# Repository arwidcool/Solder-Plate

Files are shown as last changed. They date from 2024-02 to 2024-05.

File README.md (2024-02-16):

# Solder Plate Controller with Detachable Hotplate

This repository contains the source code and design files for a Solder Plate Controller and detachable hotplate. The processor used is the ATmega4809 and is based on the work of DerSpatz. https://github.com/DerSpatz/PCB-reflow-solder-heat-plate

## Features
- Precise temperature control for soldering SMD components. with support of **up to 6 thermistors**.
- Cheap and widely available MCU- Atmega4809 and low BOM cost
- Custom PCB design with 2 versions: single area control (Completed) and 4 independent heating zones control(In works)
- Detacabale hotplate allows for use of new heatplate designs including larger ones
- Programming via USB
- PlatformIO integration for streamlined development.
- wifi via esp8266-12f module (with wifi version - In Development).
- Based on Reflow Hotplate by DerSpatz with some improvements
- Oled for menu navigation, debugging, and thermistor info
- TFT for reflow profile target and actual temp
- 4 buttons for menu navigation
- Current sense IC for current monitoring
- 3 indicator LED's. They work for both menu and REFLOW profiles (blinking while on the current stage and solid once the profile stage is complete).
- Buzzer for complete notification
- Buck- Converter for input voltage, allowing up to 24V in
- 24V+ rated input voltage stage components allowing  up to 24V to be used (Depending on powersupply trip option the "max" pwm needs to be lowered to not trip power suppply safety)
- Optional fan for cooling stage (not yet installed)
= Included are files for a case and a guard for the detachable plate terminal guard.

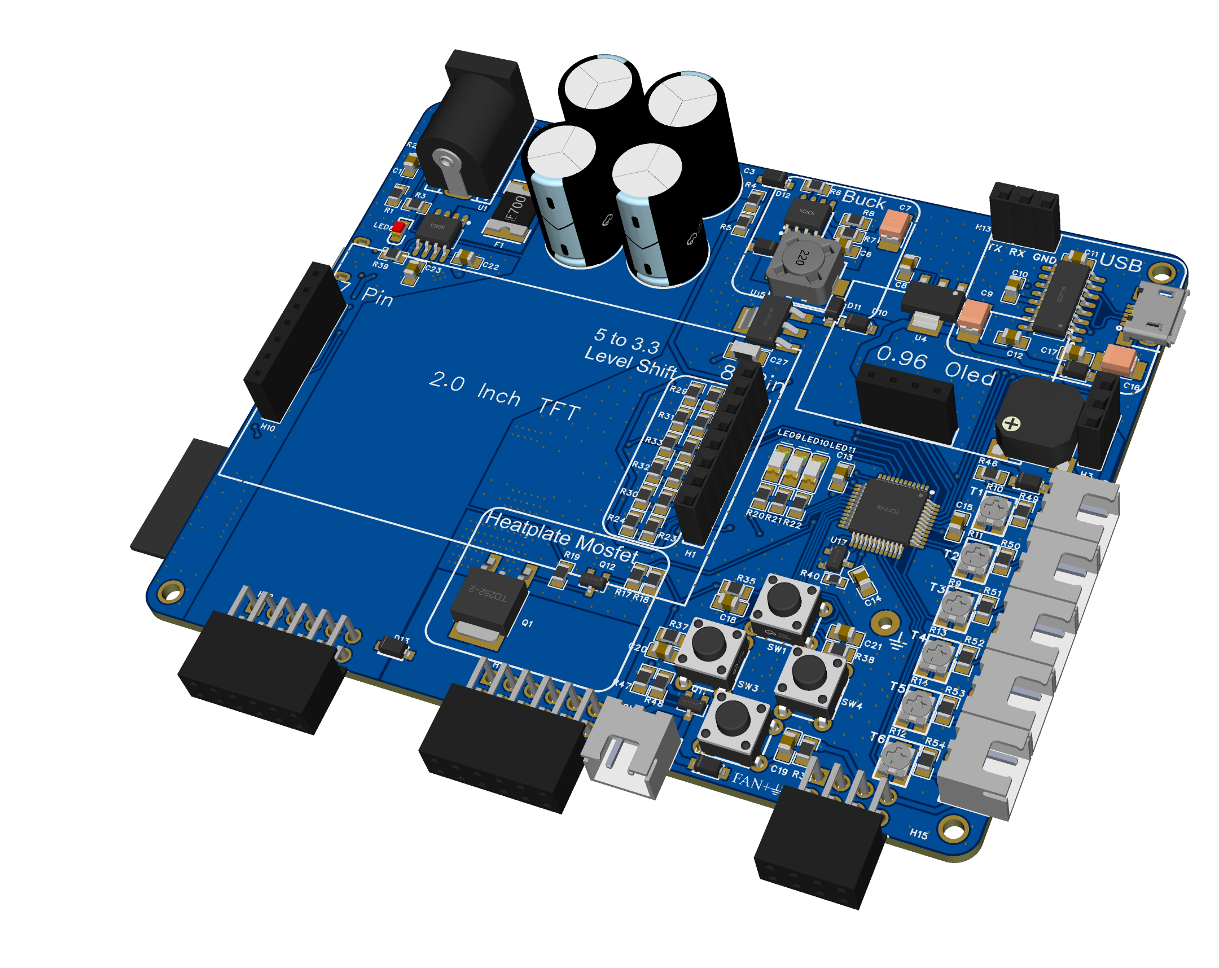
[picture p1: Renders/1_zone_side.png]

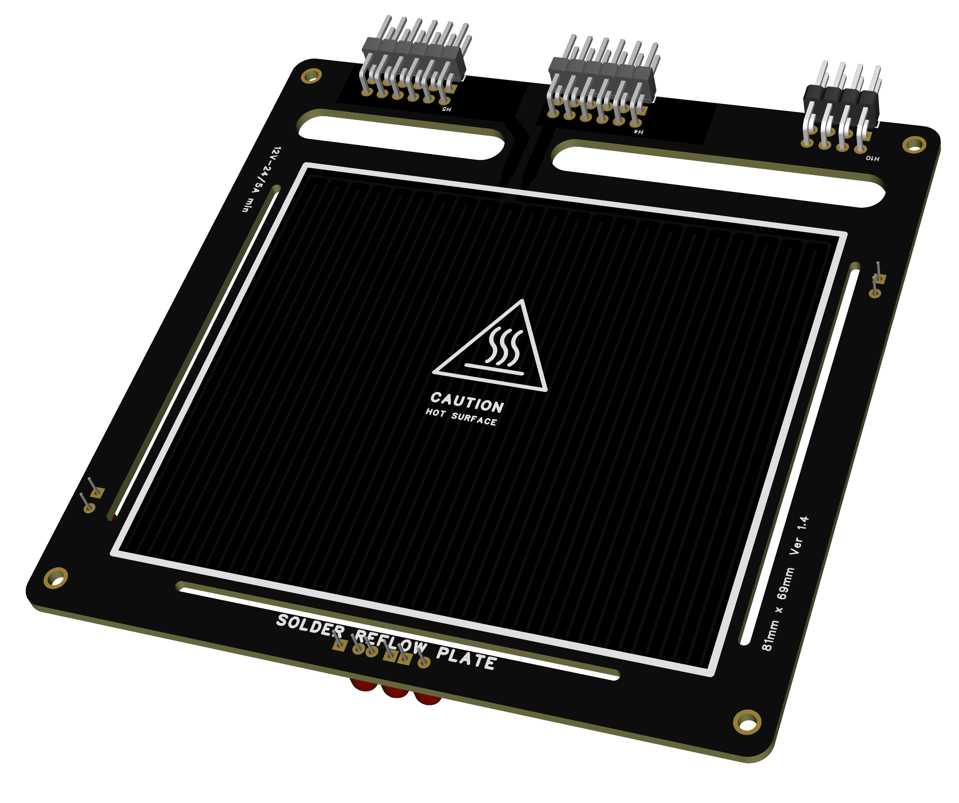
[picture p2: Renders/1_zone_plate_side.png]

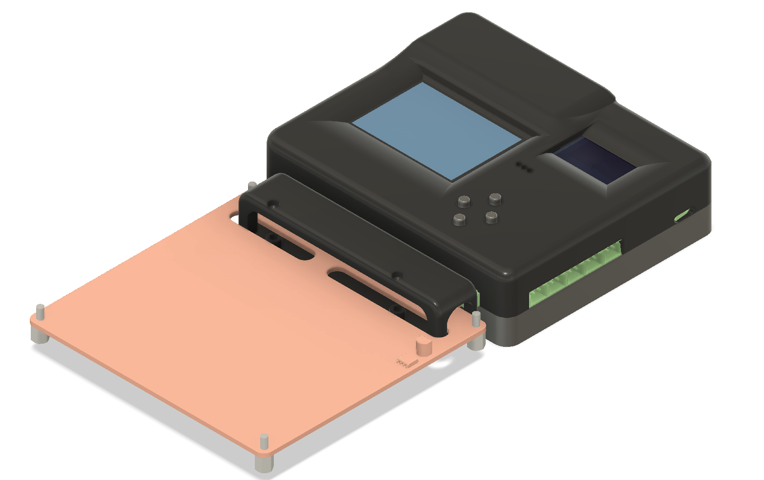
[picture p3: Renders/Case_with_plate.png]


## Getting Started

### Prerequisites

- PlatformIO Core or PlatformIO IDE.
- ATmega4809 microcontroller and all the BOM components
- Basic soldering tools and electronic assembly skills.
- Access to a PCB manufacturing service or soldering equipment (solder paste, hot air gun, tweezers)
- Some basic technical skills

### Hardware Setup

*** MAKE SURE YOU ORDER THE HOTPLATE IN BLACK. IT WILL NOT DISCOLOR AND HOLDS UP A LOT BETTER TO HEAT CYCLES ***

1. **PCB Fabrication:** Fabricate the PCB using the provided gerber files. You can use these to order the naked PCB from services like JLCPCB. 
2. **Component Assembly:** Solder the components onto the PCB as per the schematic or choose a SMT assembly service like the ones from JLCPCB
3. **Power Supply Connection:** Choose a suitable power supply. 12V 5A tested, 24v 5A compatible. Use of more then 5A requires a appropriate FUSE to be chosen and solder on place of F1

### Preparing the ATmega4809

Before programming the ATmega4809, it needs to be flashed with a default bootloader.

1. **Bootloader Flashing:**

Same process as DerSpatz Solder plate with some changes to the bootloader settingffs:

The MCU can be programmed with JTAG2UPDI (https://github.com/ElTangas/jtag2updi). For programming, you need an Arduino with ATMEGA328p (Uno or Nano), some wires, a 4.7k resistor and a 10µF capacitor or 120 Ohm resistor to disable the auto-reset.

JCM from the Discord explained the process pretty good:

- Download/Clone this project: https://github.com/ElTangas/jtag2updi and rename the folder "source" to "jtag2updi" (otherwise the Arduino IDE won't like it)
- Open jtag2updi/jtag2updi.ino in your Arduino IDE
- Configure the flasher options for your Arduino Nano and flash it
- Connect D6 of your Arduino Nano over the 4.7kOhm resistor to the UPDI pin of the board and 5V to 5V and GND to 0V
- Add the MegaCoreX hardware package to the Ardunio IDE (see https://github.com/MCUdude/MegaCoreX#how-to-install)
- Select the options for the programmer **(Board: ATmega4809, Clock: Internal 16 MHz, BOD: 2.6V or 2.7V, EEPROM: retained, Pinout: 48 pin standard, Reset pin: Reset, Bootloader:Optiboot:Uart0(Defualt pins))** and select the port of your Ardunio Nano as Port
- Make sure the programmer selected is SerialUPDI or JTAG2UPDI
- Select Burn Bootloader and see if it runs through

2. **MicroUSB Programming And Firmware Upload:**

   - **Using Platformio:**
   1. After flashing the bootloader, the ATmega4809 can be programmed via the microUSB connection using PlatformIO by building the project and upload
  
   - **Using AVRDude:**
   1. Folow instructions on : https://github.com/ElTangas/jtag2updi?tab=readme-ov-file#using-with-avrdude
   2. Example : avrdude -c jtag2updi -P com7 -p t1614
  
   - **Using AVRDUDESS (AVRDUDE with GUI interface) -- This section many not be completley finished:**
   1. Download and install AVRDUDE https://download-mirror.savannah.gnu.org/releases/avrdude/
   2. Download AVRDUDESS : https://github.com/ZakKemble/AVRDUDESS
   3. Choose the programmer as arduino
   4. Choose the MCU as ATmega4809
   5. Choose the COMPORT where the Solder Plate Controller is connected to
   6. Choose the Flash binary in the programming directory -> set to Write
   7. Choose "Write" on the Flash option and press "Go"

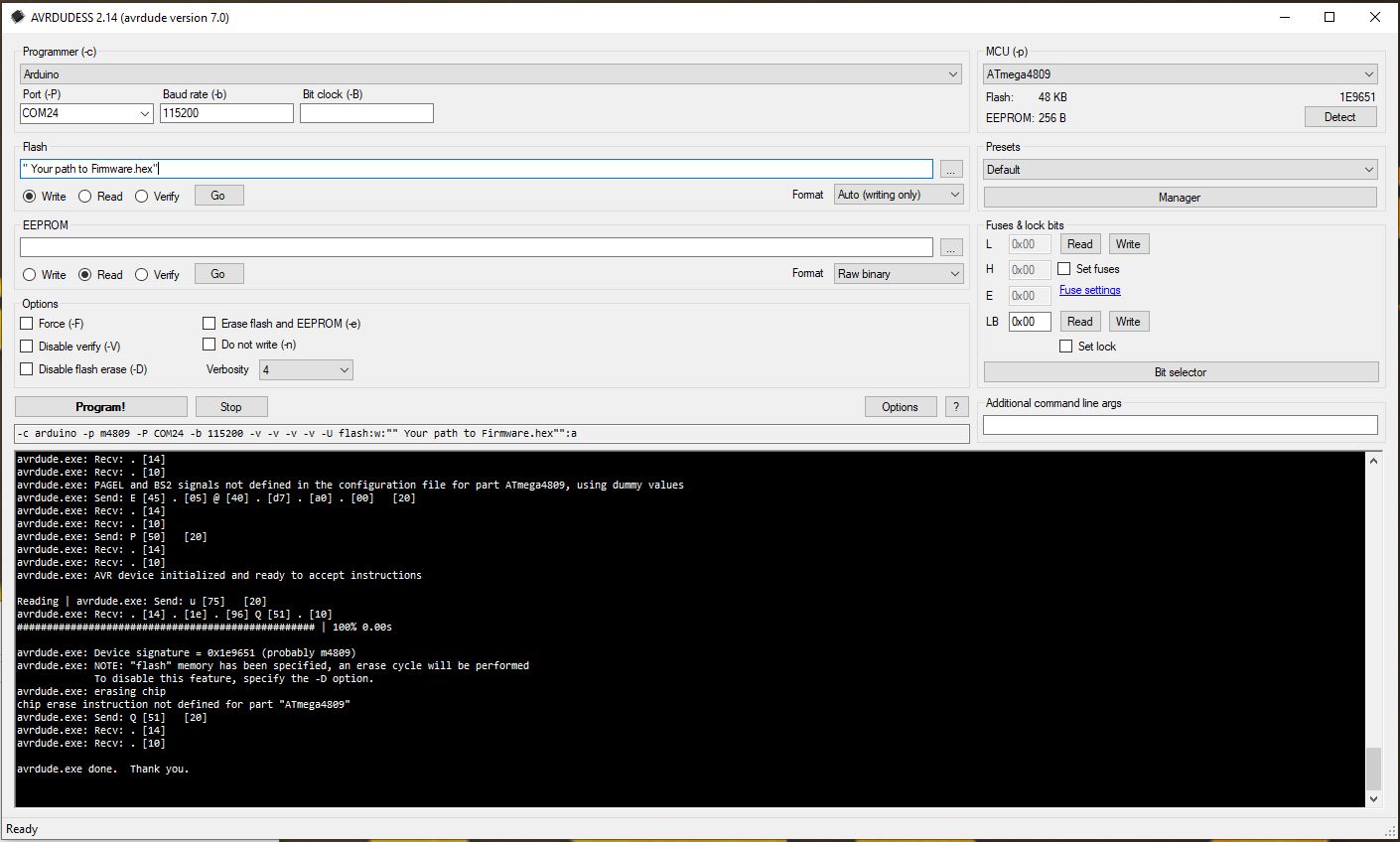
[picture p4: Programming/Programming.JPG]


3. **Setting up the controller**
   1. Order 100K NTC Glass thermistors  Use for dev was : 100K Ohm Resistor NTC 3950->  https://www.aliexpress.com/item/32862228715.html?spm=a2g0o.order_list.order_list_main.11.1f0a1802Lw8YGL
   2. Using either the potentiometer or soldering the resistor beside it choose the resistor reference value (2.5Kohm is standard)
   3. You can modify the thermistor settings in Global.ccp file, it is all explained in there
   4. Attach the sensors to the hotplate using High temp Kapton Tape
   5. Reccomended is 3 sensors on the bottom middle of plate all with 3 different refernece resistor values for accuracy across all temperature ranges and 1 thermistor held by a pair of helping hangs placed so the head touches somewhere on the PCB to be refllowed
   By default this is set as thermistor 1:
   6. Link to 2.0 inch TFT -> https://www.aliexpress.com/item/1005002363748586.html?spm=a2g0o.order_list.order_list_main.5.165d1802Amz1I7  (8 pin version) -> 7 Pin version can also be used 
   7. Link to 0.96 OLED -> https://www.aliexpress.com/item/32957309383.html?spm=a2g0o.order_list.order_list_main.17.662c1802iqqiSE  (Choose OLD design SSD1306)

   *** IMPORTANT: Thermistors 1 is ONLY available on the hotplate. Thermistor 6 is only available on the controller via connector 5**

   You can solder the thermistors directly on the hotplatte or use them with the connector. Please update the thermistor settings to the way you have them set-up.

   Here are the defualt thermistor settings, The assume that the thermistors are soldered on the plate for 1,2,3: 
   Thermistors 6 on the connector number 5, touching the PCB to be soldered.

   Thermistor thermistor1(THERMISTOR1_PIN, 2545, ThermistorZ_Placement::ON_PCB, ThermistorXY_Placement::MIDDLE);          // -> 2545ohm set refrence -> This thermistor is set directly touching the PCB to be soldered
   Thermistor thermistor2(THERMISTOR2_PIN, 9100, ThermistorZ_Placement::BOTTOM, ThermistorXY_Placement::MIDDLE_LOW_TEMP);          //- > 9100 ohm set refrence Best accuracy around 90C -> This thermistor is used for the lower end of the temp scale  
   Thermistor thermistor3(THERMISTOR3_PIN, 2040, ThermistorZ_Placement::BOTTOM, ThermistorXY_Placement::MIDDLE); // -> 2.5Kohm best middleground
   Thermistor thermistor4(THERMISTOR4_PIN, 564, ThermistorZ_Placement::BOTTOM, ThermistorXY_Placement::MIDDLE_HIGH_TEMP); //-> 564Kohm set refrence // 564R reference = Best accuracy around 210C

   If you wish to only use the connectors use 2,3,4 and update the Globals .cpp to match your settings
      
   The set resistence is measured between a GND point anywhere on the board and the LEFT pin of the connector with the thermistor UNPLUGGED and the MODULE POWERED OFF!!!!

   you can measure and set those to the preset values or modify the values in globals.ccp to match your thermistors.

   If a thermistor is set to bottom a automatic scaling factor for the difference difference in plate temp is set that was aquired through lots of datalogging and computations

   If a thermistor is set to SIDE there is no scaling factor and will throw off the reading acorss the center of the plate (overall will be lower)

   When using the Thermistor with placement "ON_PCB" That thermistor has a weighting factor of 10 and has the biggest effect on the read temperature.

   The normal weighting factor is between 0.1 and 1.5 for the others.

### Software Installation

1. **Clone the Repository:**
   ```bash
   git clone https://github.com/arwidcool/Solder-Plate
   cd Solder-Plate
2. **Import in vscode**
To open a PlatformIO project in VSCode with the PlatformIO extension, follow these steps:

1. Launch VSCode and ensure that you have the PlatformIO extension installed. If not, you can install it from the VSCode marketplace.
2. Open the VSCode command palette by pressing Ctrl+Shift+P (Windows/Linux) or Cmd+Shift+P (Mac).
3. In the command palette, type "PlatformIO: Open" and select the "PlatformIO: Open" command from the list.
4. Navigate to the root folder of your PlatformIO project using the file explorer that appears.
5. Select the folder and click "Open" to open the PlatformIO project in VSCode.

### Usage

Power On: Connect the controller with a 12V 5A(Tested working) or 24V 5A PSU (Untested)
Set Profile: Navigate the menu and choose the desired reflow profile
Start Soldering: Place your PCB and components on the hotplate and start the profile

### Customization

Feel free to modify the firmware and PCB design to suit your specific needs.

### Contributing
Contributions are welcome. Please follow standard procedures for contributing to open-source projects.

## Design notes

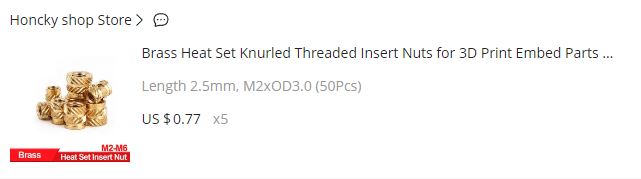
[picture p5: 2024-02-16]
Hardware/Case 3D Files/Inserts.JPG

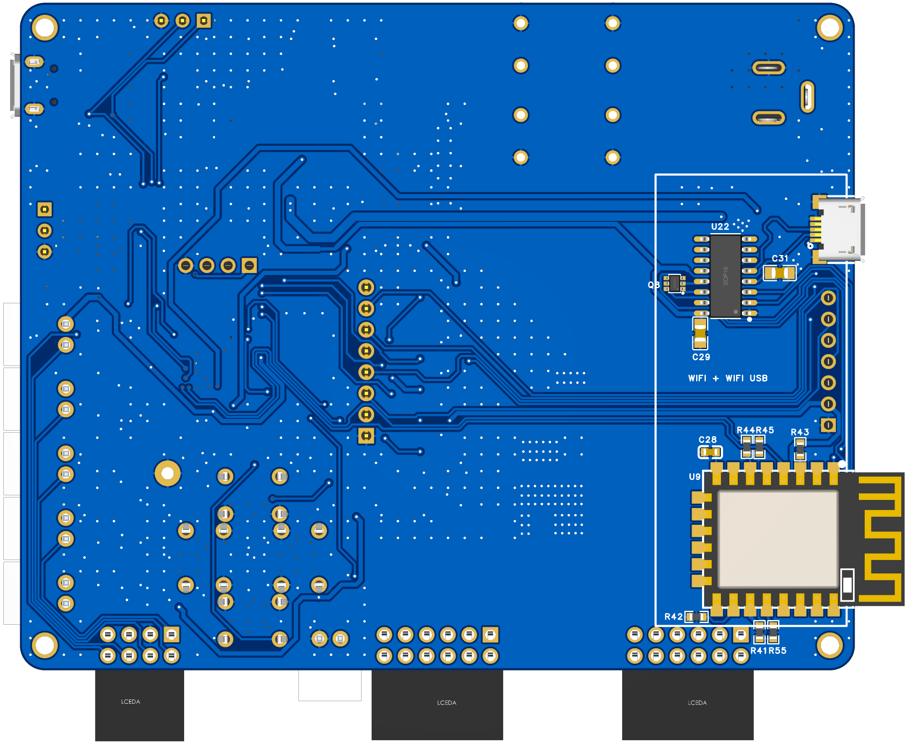
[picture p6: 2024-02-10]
Renders/1 zone back.png

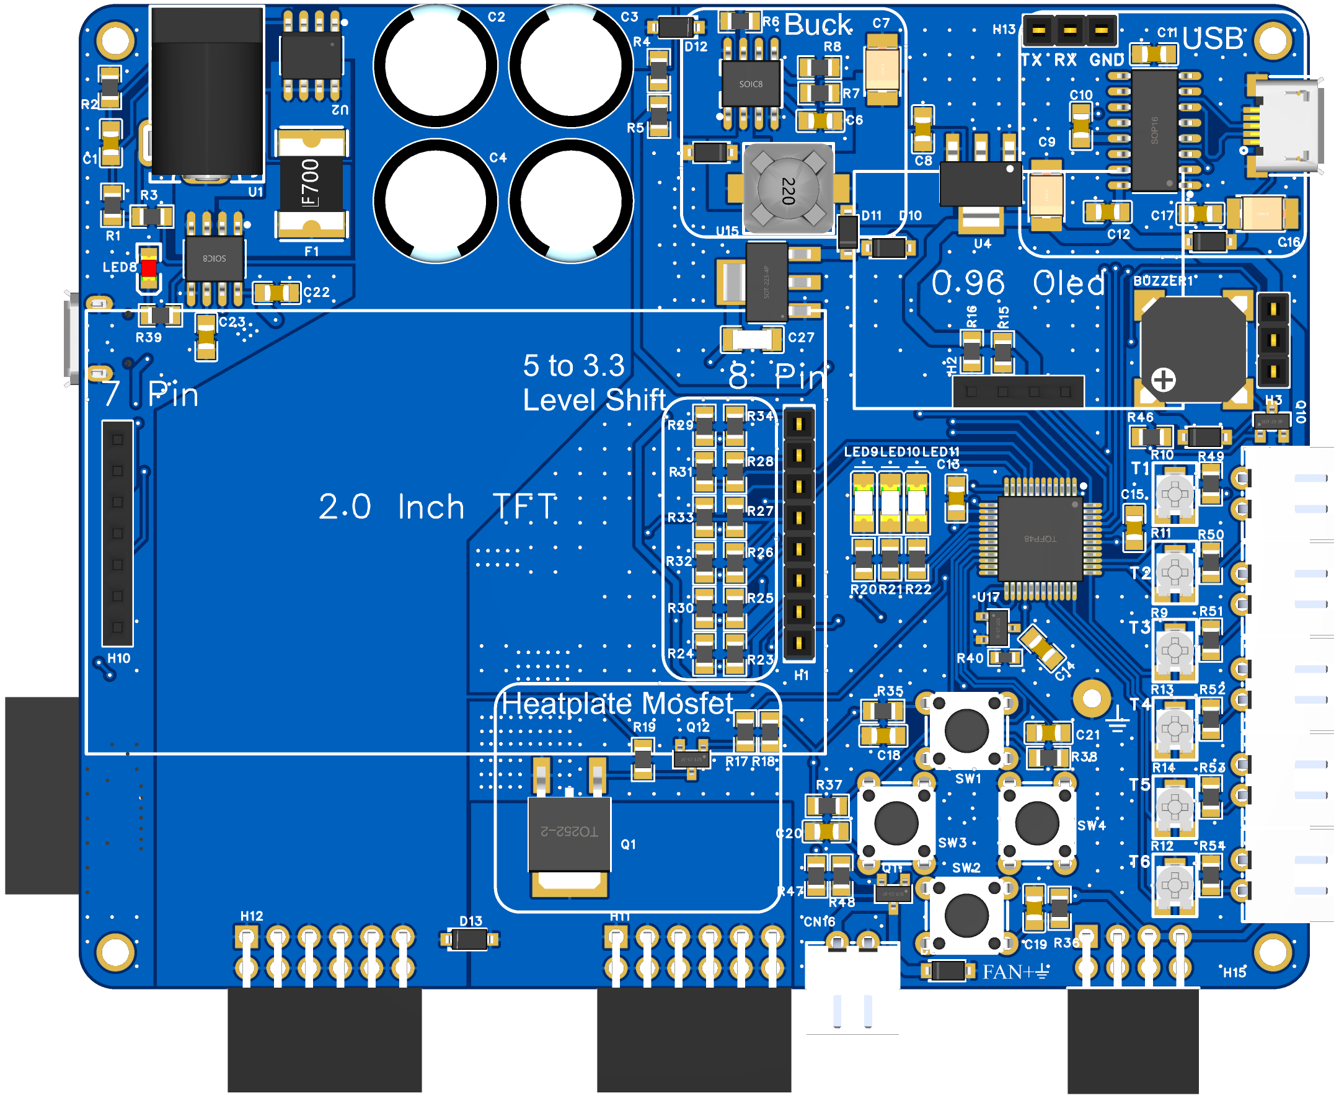
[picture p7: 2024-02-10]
Renders/1 zone top.png

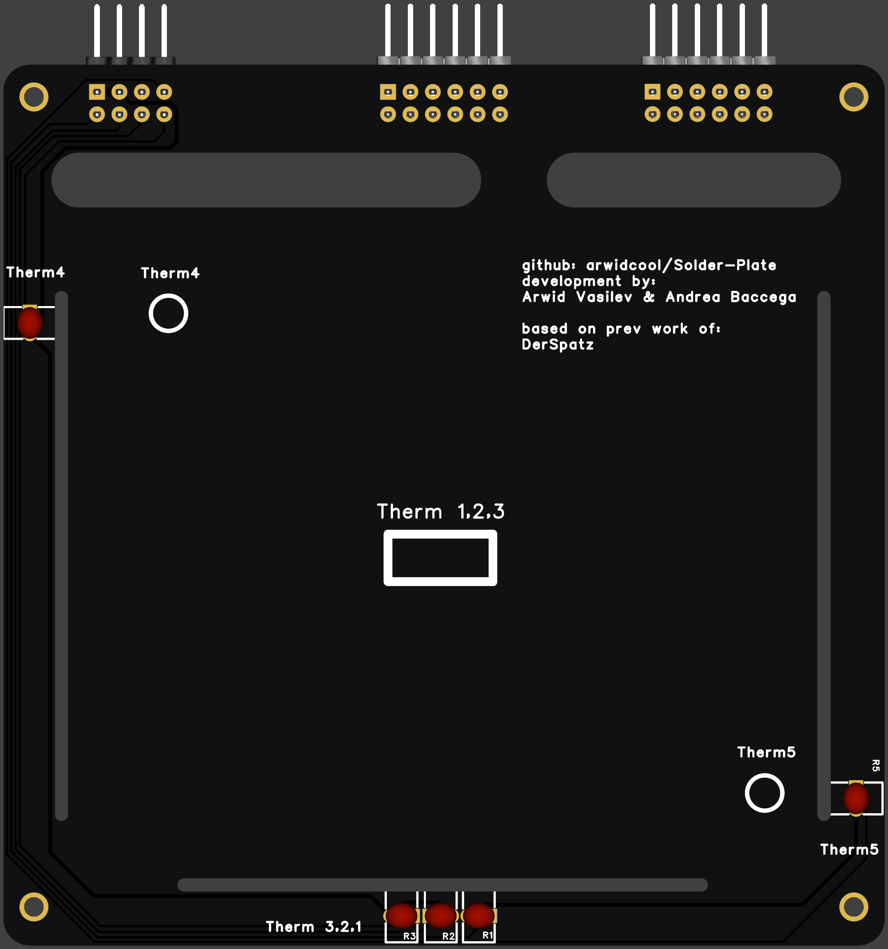
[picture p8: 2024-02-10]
Renders/1 zone plate back.png

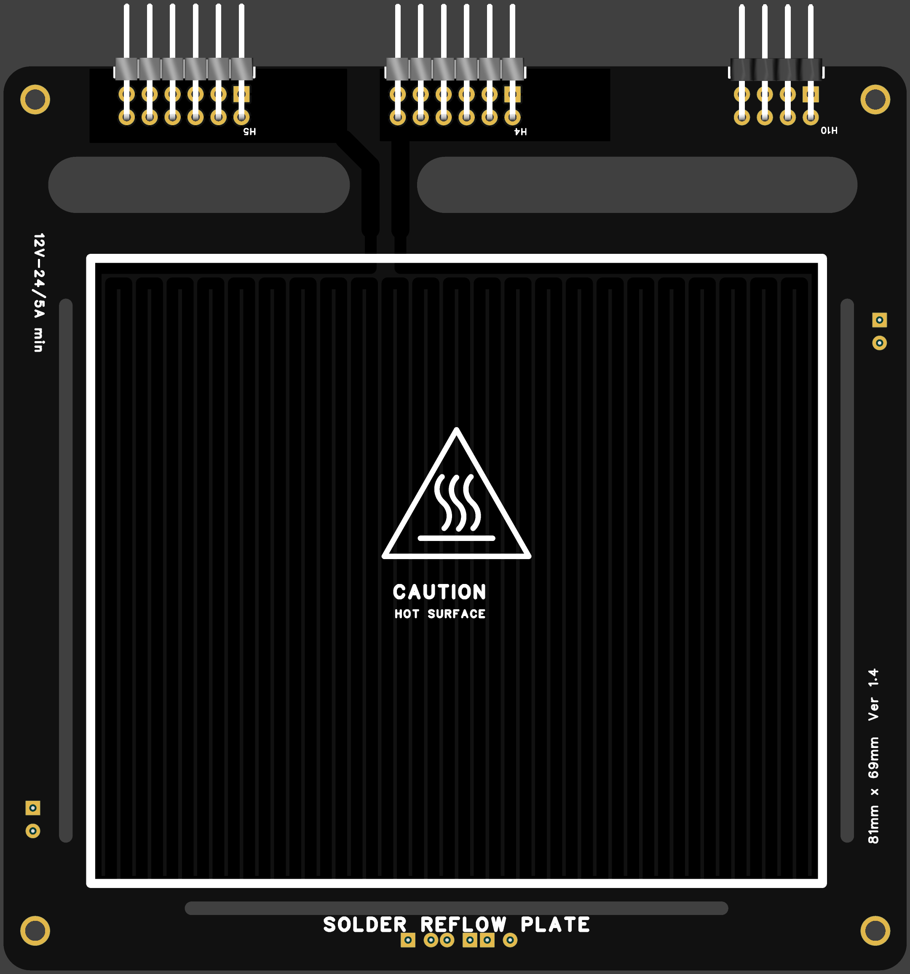
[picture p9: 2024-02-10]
Renders/1_zone_plate_top.png

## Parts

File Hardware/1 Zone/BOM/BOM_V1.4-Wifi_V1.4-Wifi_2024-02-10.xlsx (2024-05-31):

No. | Quantity | Comment | Designator | Footprint | Value | Manufacturer Part | Manufacturer | Supplier Part | Supplier | Pins | Supplier Footprint | Rated Voltage | Device | LCSC Price
1 | 1 | 2700Hz | BUZZER1 | BUZ-SMD_4P-L8.5-W8.5-P8.50-BR | 2700Hz | MLT-8530 | 华能 | C94599 | LCSC | 4 | SMD | 3.6V | MLT-8530 | 0.2334
2 | 1 | 10uF | C1 | C0805 | 10uF |  |  |  |  | 2 | 0805 |  | CAP_0805
3 | 4 | 680uF | C2,C3,C4,C5 | CAP-TH_BD10.0-P5.00-D1.0-FD | 680uF | GR687M035G20RR0VL4FP0 | CX(承兴) | C23777 | LCSC | 2 | 插件,D10xL20mm |  | GR687M035G20RR0VL4FP0
4 | 1 | 220pF | C6 | C0805 | 220pF |  |  |  |  | 2 | 0805 |  | CAP_0805
5 | 3 | 100uF | C7,C9,C16 | CAP-SMD_L3.5-W2.8-R-RD | 100uF | TC212B107M010B | Sunlord(顺络) | C124859 | LCSC | 2 | CASE-B-3528 |  | TC212B107M010B | 0.2471
6 | 1 | 22uF | C8 | C0805 | 22uF |  |  |  |  | 2 | 0805 |  | CAP_0805
7 | 13 | 100nF | C10,C11,C12,C13,C14,C15,C18,C19,C20,C21,C22,C29,C31 | C0805 | 100nF |  |  |  |  | 2 | 0805 |  | CAP_0805
8 | 1 | 4.7uF | C17 | C0805 | 4.7uF |  |  |  |  | 2 | 0805 |  | CAP_0805
9 | 1 | 1nF | C23 | C0805 | 1nF |  |  |  |  | 2 | 0805 |  | CAP_0805
10 | 1 | 100uF | C27 | C1206 | 100uF | CL31A107MQHNNNE | SAMSUNG(三星) | C15008 | LCSC | 2 | 1206 |  | CL31A107MQHNNNE
11 | 1 | 100nF | C28 | C0603 | 100nF |  |  |  |  | 2 | 0603 |  | CAP_0603
12 | 6 | HX25003-2WAP | CN11,CN12,CN13,CN14,CN15,CN16 | CONN-TH_2P-P2.50_HX25003-2WAP |  | HX25003-2WAP | HX(红星) | C442326 | LCSC | 2 | 弯插,P=2.5mm |  | HX25003-2WAP | 0.0131
13 | 6 | MBR0520 | D1,D6,D7,D8,D10,D11 | SOD-123_L2.8-W1.8-LS3.7-RD |  | MBR0520 | CJ(江苏长电/长晶) | C77335 | LCSC | 2 | SOD-123 |  | MBR0520_C77335 | 0.0335
14 | 2 | B5819W | D12,D13 | SOD-123_L2.7-W1.6-LS3.7-RD-1 |  | B5819W |  | C179553 | LCSC | 2 | SOD-123 |  | B5819W
15 | 1 | SMD500L-30V | F1 | F2920 |  | SMD500L-30V | 台湾陆海 |  |  | 2 | 2920 |  | SMD250L-30V
16 | 1 |  | H1 | HDR-TH_8P-P2.54-V-F-1 |  |  |  |  |  | 8 | Through |  | HDR-F_2.54_1x8P
17 | 1 | 2.54-1*4P母 | H2 | HDR-TH_4P-P2.54-V-F |  | 2.54-1*4P母 | BOOMELE(博穆精密) | C2718488 | LCSC | 4 | Through |  | HDR-F_2.54_1x4P | 0.0436
18 | 2 | PM254V-11-03-H85 | H3,H13 | HDR-TH_3P-P2.54-V-F |  | PM254V-11-03-H85 | XFCN(兴飞) | C541850 | LCSC | 3 | Through |  | HDR-F_2.54_1x3P | 0.0948
19 | 1 | B-2200S07P-A120 | H10 | HDR-TH_7P-P2.54-V-F |  | B-2200S07P-A120 | Ckmtw(灿科盟) | C124418 | LCSC | 7 | Through |  | HDR-F_2.54_1x7P | 0.1426
20 | 2 | A2541HWR-2x6P | H11,H12 | HDR-TH_12P-P2.54-H-F-R2-C6-S2.54-W10.2 |  | A2541HWR-2x6P | CJT(长江连接器) | C5333437 | LCSC | 12 | 弯插,P=2.5mm |  | A2541HWR-2x6P_1 | 0.2818
21 | 1 | A2541HWR-2x4P | H15 | HDR-TH_8P-P2.54-H-F-R2-C4-S2.54-W10.2 |  | A2541HWR-2x4P | CJT(长江连接器) | C239355 | LCSC | 8 | 弯插,P=2.54mm |  | A2541HWR-2x4P | 0.1904
22 | 1 | 220uH | L1 | IND-SMD_L7.3-W7.3_CDRH74 | 220uH | 220uH (CD74R-221) | https://www.aliexpress.com/item/1005005453639618.html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 | AliExpress | N/A | 2 | SMD,7.3x7.3mm |  | CDRH74-221MT
23 | 1 |  | LED8 | LED0805-RD_GREEN |  |  |  |  |  | 2 | 0805 |  | LED_0805-R
24 | 1 | LED_Y | LED9 | LED1206-RD |  | LED_Y | 国星光电 | C130716 | LCSC | 2 | 1206 |  | NCD1206O1 | 0.0356
25 | 1 | LED_R | LED10 | LED1206-RD |  | LED_R | 国星光电 | C130716 | LCSC | 2 | 1206 |  | NCD1206O1 | 0.0356
26 | 1 | LED_G | LED11 | LED1206-RD |  | LED_G | 国星光电 | C130716 | LCSC | 2 | 1206 |  | NCD1206O1 | 0.0356
27 | 1 | AOD4184A | Q1 | TO-252-2_L6.6-W6.1-P4.57-LS9.9-TL-CW |  | AOD4184A | AOS | C99124 | LCSC | 3 | TO-252-2(DPAK) |  | AOD4184A | 0.3088
28 | 1 | UMH3NTN | Q8 | SOT-363_L2.0-W1.3-P0.65-LS2.1-TL |  | UMH3NTN | ROHM(罗姆) | C123008 | LCSC | 6 | SOT-323-6 |  | UMH3NTN | 0.0431
29 | 1 | IRLML2502 | Q10 | SOT-23_L2.9-W1.3-P1.90-LS2.4-BR |  | IRLML2502 | UMW(友台半导体) | C347503 | LCSC | 3 | SOT-23 |  | IRLML2502_C347503 | 0.0707
30 | 1 | SI2300 | Q11 | SOT-23-3_L2.9-W1.3-P0.95-LS2.4-BR |  | SI2300 | KUU | C2985622 | LCSC | 3 | SOT-23 |  | SI2300 | 0.0273
31 | 1 | S8050 | Q12 | SOT-23-3_L2.9-W1.3-P1.90-LS2.4-BR |  | S8050 | JSMSEMI(杰盛微) | C916390 | LCSC | 3 | SOT-23 |  | S8050_C916390 | 0.0050
32 | 2 | 47R | R1,R3 | R0805 | 47R |  |  |  |  | 2 | 0805 |  | Res_0805
33 | 14 | 10K | R2,R18,R24,R29,R30,R31,R32,R33,R35,R36,R37,R38,R46,R48 | R0805 | 10K |  |  |  |  | 2 | 0805 |  | Res_0805
34 | 10 | 4.7K | R4,R15,R16,R19,R23,R25,R26,R27,R28,R34 | R0805 | 4.7K |  |  |  |  | 2 | 0805 |  | Res_0805
35 | 5 | 1K | R5,R17,R20,R21,R39 | R0805 | 1K |  |  |  |  | 2 | 0805 |  | Res_0805
36 | 1 | .33R | R6 | R0805 | .33R |  |  |  |  | 2 | 0805 |  | Res_0805
37 | 1 | 7.5K | R7 | R0805 | 7.5K |  |  |  |  | 2 | 0805 |  | Res_0805
38 | 1 | 1.5K | R8 | R0805 | 1.5K |  |  |  |  | 2 | 0805 |  | Res_0805
39 | 6 | 15K | R9,R10,R11,R12,R13,R14 | RES-ADJ-SMD_VG039NCHXTB153 | 15K | VG039NCHXTB153 | HDK(北陆电气) |  | LCSC | 3 | SMD-3P,3x3.8mm |  | VG039NCHXTB153
40 | 4 | 2K | R22,R50,R51,R53 | R0805 | 2K |  |  |  |  | 2 | 0805 |  | Res_0805
41 | 1 | 750R | R40 | R0603 | 750R |  |  |  |  | 2 | 0603 |  | Res_0603
42 | 4 | 10K | R41,R42,R43,R55 | R0603 | 10K |  |  |  |  | 2 | 0603 |  | Res_0603
43 | 1 | 1K | R44 | R0603 | 1K |  |  |  |  | 2 | 0603 |  | Res_0603
44 | 1 | 3.6K | R45 | R0603 | 3.6K |  |  |  |  | 2 | 0603 |  | Res_0603
45 | 1 | 100R | R47 | R0805 | 100R |  |  |  |  | 2 | 0805 |  | Res_0805
46 | 3 | 15K | R49,R52,R54 | R0805 | 15K |  |  |  |  | 2 | 0805 |  | Res_0805
47 | 4 | K2-1102DP-G3SW-04 | SW1,SW2,SW3,SW4 | KEY-TH_4P-L6.0-W6.0-P4.50-LS6.5 |  | K2-1102DP-G3SW-04 | 韩国韩荣 | C136682 | LCSC | 4 | 插件 |  | K2-1102DP-G3SW-04 | 0.0541
48 | 1 | POWER-JACK | U1 | DC-IN-TH_POWER-JACK |  | POWER-JACK |  | C9900001795 | LCSC | 3 | DC-IN-TH_POWER-JACK |  | POWER-JACK
49 | 1 | AO4409 | U2 | SOP-8_L4.9-W3.9-P1.27-LS6.0-BL |  | AO4409 | TECHPUBLIC(台舟) | C7603375 | LCSC | 8 | SOP-8 |  | AO4409_C7603375 | 0.2139
50 | 1 | AMS1117-5.0 | U4 | SOT-223-3_L6.7-W3.7-P2.30-LS7.0-BR |  | AMS1117-5.0 | JSMSEMI(杰盛微) | C917153 | LCSC | 4 | SOT-223-3 |  | AMS1117-5.0_C917153 | 0.0957
51 | 1 | WT8266-S5ESP-12F | U9 | WIFIM-SMD_22P-L24.0-W16.0-P2.00 |  | WT8266-S5ESP-12F | Wireless-tag(启明云端) | C477829 | LCSC | 22 | SMD |  | WT8266-S5 ESP-12F | 2.4326
52 | 2 | CH340C | U11,U22 | SOP-16_L10.0-W3.9-P1.27-LS6.0-BL |  | CH340C | WCH(南京沁恒) | C84681 | LCSC | 16 | SOP-16 |  | CH340C | 0.4996
53 | 1 | AMS1117-3.3 | U15 | SOT-223-3_L6.5-W3.4-P2.30-LS7.0-BR |  | AMS1117-3.3 | AMS | C6186 | LCSC | 4 | SOT-223 |  | AMS1117-3.3_C6186
54 | 1 | MC34063ECD-TR | U16 | SOIC-8_L5.0-W4.0-P1.27-LS6.0-BL |  | MC34063ECD-TR | ST(意法半导体) | C65110 | LCSC | 8 | SOIC-8-150mil |  | MC34063ECD-TR
55 | 1 | LM4040DIM3-2.5+T | U17 | SOT-23-3_L2.9-W1.6-P1.90-LS2.8-BR |  | LM4040DIM3-2.5+T | ADI(亚德诺) | C2156551 | LCSC | 3 | SOT-23 |  | LM4040DIM3-2.5+T | 0.5378
56 | 1 | ATMEGA4809-AFR | U18 | TQFP-48_L7.0-W7.0-P0.50-LS9.0-BL |  | ATMEGA4809-AFR | MICROCHIP(美国微芯) | C189475 | LCSC | 48 | TQFP-48(7x7) |  | ATMEGA4809-AFR | 3.9137
57 | 1 | ACS712ELCTR-20A-T | U20 | SOIC-8_L4.9-W3.9-P1.27-LS6.0-BL |  | ACS712ELCTR-20A-T | ALLEGRO(美国埃戈罗) | C10681 | LCSC | 8 | SOP-8 |  | ACS712ELCTR-20A-T
58 | 2 | U254-051T-4BH83-S1S | USB1,USB2 | MICRO-USB-SMD_U254-051T-4BH83-S1S |  | U254-051T-4BH83-S1S | XKBConnectivity(中国星坤) | C319160 | LCSC | 6 | SMD |  | U254-051T-4BH83-S1S | 0.0672
59 | 2 | PZ254-2-06-W-8.5 | H4,H5 | HDR-TH_12P-P2.54-H-M-R2-C6-S2.54-N |  | PZ254-2-06-W-8.5 | HCTL(华灿天禄) | C2894986 | LCSC | 12 | 插件,P=2.54mm |  | PZ254-2-06-W-8.5 | 0.1796
60 | 1 | PZ254-2-04-W-8.5 | H10 | HDR-TH_8P-P2.54-H-M-R2-C4-S2.54-N |  | PZ254-2-04-W-8.5 | HCTL(华灿天禄) | C2894984 | LCSC | 8 | 插件,P=2.54mm |  | PZ254-2-04-W-8.5 | 0.1154

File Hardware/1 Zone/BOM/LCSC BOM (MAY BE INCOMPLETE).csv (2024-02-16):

LCSC Part Number | Manufacture Part Number | Manufacturer | Package | Customer # | Description | RoHS | Order Qty. | Min\Mult Order Qty. | Unit Price | Ext.Price | Product Link
C19078762 | 2920L500/24GR | LUTE | 2920 | F1 | 24V 5A 40A 10A 2920 Resettable Fuses ROHS | yes | 1 | 5 | 0.1849 | 0.18 | https://assets.lcsc.com/images/lcsc/96x96/20231113_LUTE-2920L500-24GR_C19078762_front.jpg
C2932476 | CL21A106KBYQNNE | Samsung Electro-Mechanics | 0805 |  | 50V 10uF X5R ±10% 0805 Multilayer Ceramic Capacitors MLCC - SMD/SMT ROHS | yes | 1 | 10 | 0.0686 | 0.07 | https://assets.lcsc.com/images/lcsc/96x96/20230122_Samsung-Electro-Mechanics-CL21A106KBYQNNE_C2932476_front.jpg
C61747 | CL21C221JBANNNC | Samsung Electro-Mechanics | 0805 |  | 50V 220pF C0G ±5% 0805 Multilayer Ceramic Capacitors MLCC - SMD/SMT ROHS | yes | 1 | 50 | 0.0137 | 0.01 | https://assets.lcsc.com/images/lcsc/96x96/20221230_Samsung-Electro-Mechanics-CL21C221JBANNNC_C61747_front.jpg
C6119901 | CGA0805X5R226M350MT | HRE | 0805 |  | 35V 22uF X5R ±20% 0805 Multilayer Ceramic Capacitors MLCC - SMD/SMT ROHS | yes | 1 | 5 | 0.1296 | 0.13 | https://assets.lcsc.com/images/lcsc/96x96/20230729_HRE-CGA0805X5R226M350MT_C6119901_front.jpg
C1711 | CL21B104KBCNNNC | Samsung Electro-Mechanics | 0805 |  | 50V 100nF X7R ±10% 0805 Multilayer Ceramic Capacitors MLCC - SMD/SMT ROHS | yes | 13 | 100 | 0.0069 | 0.09 | https://assets.lcsc.com/images/lcsc/96x96/20221227_Samsung-Electro-Mechanics-CL21B104KBCNNNC_C1711_front.jpg
C98192 | CL21A475KBQNNNE | Samsung Electro-Mechanics | 0805 |  | 50V 4.7uF X5R ±10% 0805 Multilayer Ceramic Capacitors MLCC - SMD/SMT ROHS | yes | 1 | 20 | 0.0238 | 0.02 | https://assets.lcsc.com/images/lcsc/96x96/20221231_Samsung-Electro-Mechanics-CL21A475KBQNNNE_C98192_front.jpg
C46653 | CL21B102KBCNNNC | Samsung Electro-Mechanics | 0805 |  | 50V 1nF X7R ±10% 0805 Multilayer Ceramic Capacitors MLCC - SMD/SMT ROHS | yes | 1 | 50 | 0.0079 | 0.01 | https://assets.lcsc.com/images/lcsc/96x96/20221230_Samsung-Electro-Mechanics-CL21B102KBCNNNC_C46653_front.jpg
C1591 | CL10B104KB8NNNC | Samsung Electro-Mechanics | 0603 |  | 50V 100nF X7R ±10% 0603 Multilayer Ceramic Capacitors MLCC - SMD/SMT ROHS | yes | 1 | 100 | 0.0026 | 0.01 | https://assets.lcsc.com/images/lcsc/96x96/20221227_Samsung-Electro-Mechanics-CL10B104KB8NNNC_C1591_front.jpg
C17714 | 0805W8F470JT5E | UNI-ROYAL(Uniroyal Elec) | 0805 |  | 125mW Thick Film Resistors 150V ±1% ±200ppm/? 47? 0805 Chip Resistor - Surface Mount ROHS | yes | 2 | 100 | 0.0018 | 0.01 | https://assets.lcsc.com/images/lcsc/96x96/20221228_UNI-ROYAL-Uniroyal-Elec-0805W8F470JT5E_C17714_front.jpg
C17414 | 0805W8F1002T5E | UNI-ROYAL(Uniroyal Elec) | 0805 |  | 125mW Thick Film Resistors 150V ±100ppm/? ±1% 10k? 0805 Chip Resistor - Surface Mount ROHS | yes | 14 | 100 | 0.0014 | 0.02 | https://assets.lcsc.com/images/lcsc/96x96/20221228_UNI-ROYAL-Uniroyal-Elec-0805W8F1002T5E_C17414_front.jpg
C17673 | 0805W8F4701T5E | UNI-ROYAL(Uniroyal Elec) | 0805 |  | 125mW Thick Film Resistors 150V ±100ppm/? ±1% 4.7k? 0805 Chip Resistor - Surface Mount ROHS | yes | 10 | 100 | 0.0018 | 0.02 | https://assets.lcsc.com/images/lcsc/96x96/20230217_UNI-ROYAL-Uniroyal-Elec-0805W8F4701T5E_C17673_front.jpg
C17513 | 0805W8F1001T5E | UNI-ROYAL(Uniroyal Elec) | 0805 |  | 125mW Thick Film Resistors 150V ±100ppm/? ±1% 1k? 0805 Chip Resistor - Surface Mount ROHS | yes | 5 | 100 | 0.0018 | 0.01 | https://assets.lcsc.com/images/lcsc/96x96/20221228_UNI-ROYAL-Uniroyal-Elec-0805W8F1001T5E_C17513_front.jpg
C52548 | 0805W8F330LT5E | UNI-ROYAL(Uniroyal Elec) | 0805 |  | 125mW Thick Film Resistors 150V ±800ppm/? ±1% 330m? 0805 Chip Resistor - Surface Mount ROHS | yes | 1 | 100 | 0.0035 | 0.01 | https://assets.lcsc.com/images/lcsc/96x96/20221230_UNI-ROYAL-Uniroyal-Elec-0805W8F330LT5E_C52548_front.jpg
C17807 | 0805W8F7501T5E | UNI-ROYAL(Uniroyal Elec) | 0805 |  | 125mW Thick Film Resistors 150V ±100ppm/? ±1% 7.5k? 0805 Chip Resistor - Surface Mount ROHS | yes | 1 | 100 | 0.0018 | 0.01 | https://assets.lcsc.com/images/lcsc/96x96/20221228_UNI-ROYAL-Uniroyal-Elec-0805W8F7501T5E_C17807_front.jpg
C4310 | 0805W8F1501T5E | UNI-ROYAL(Uniroyal Elec) | 0805 |  | 125mW Thick Film Resistors 150V ±100ppm/? ±1% 1.5k? 0805 Chip Resistor - Surface Mount ROHS | yes | 1 | 100 | 0.0018 | 0.01 | https://assets.lcsc.com/images/lcsc/96x96/20230331_UNI-ROYAL-Uniroyal-Elec-0805W8F1501T5E_C4310_front.jpg
C17604 | 0805W8F2001T5E | UNI-ROYAL(Uniroyal Elec) | 0805 |  | 125mW Thick Film Resistors 150V ±100ppm/? ±1% 2k? 0805 Chip Resistor - Surface Mount ROHS | yes | 4 | 100 | 0.0018 | 0.01 | https://assets.lcsc.com/images/lcsc/96x96/20221228_UNI-ROYAL-Uniroyal-Elec-0805W8F2001T5E_C17604_front.jpg
C23241 | 0603WAF7500T5E | UNI-ROYAL(Uniroyal Elec) | 0603 |  | 100mW Thick Film Resistors 75V ±100ppm/? ±1% 750? 0603 Chip Resistor - Surface Mount ROHS | yes | 1 | 100 | 0.0010 | 0.01 | https://assets.lcsc.com/images/lcsc/96x96/20221229_UNI-ROYAL-Uniroyal-Elec-0603WAF7500T5E_C23241_front.jpg
C25804 | 0603WAF1002T5E | UNI-ROYAL(Uniroyal Elec) | 0603 |  | 100mW Thick Film Resistors 75V ±100ppm/? ±1% 10k? 0603 Chip Resistor - Surface Mount ROHS | yes | 4 | 100 | 0.0010 | 0.01 | https://assets.lcsc.com/images/lcsc/96x96/20221229_UNI-ROYAL-Uniroyal-Elec-0603WAF1002T5E_C25804_front.jpg
C21190 | 0603WAF1001T5E | UNI-ROYAL(Uniroyal Elec) | 0603 |  | 100mW Thick Film Resistors 75V ±100ppm/? ±1% 1k? 0603 Chip Resistor - Surface Mount ROHS | yes | 1 | 100 | 0.0008 | 0.01 | https://assets.lcsc.com/images/lcsc/96x96/20221229_UNI-ROYAL-Uniroyal-Elec-0603WAF1001T5E_C21190_front.jpg
C22980 | 0603WAF3601T5E | UNI-ROYAL(Uniroyal Elec) | 0603 |  | 100mW Thick Film Resistors 75V ±100ppm/? ±1% 3.6k? 0603 Chip Resistor - Surface Mount ROHS | yes | 1 | 100 | 0.0011 | 0.01 | https://assets.lcsc.com/images/lcsc/96x96/20230218_UNI-ROYAL-Uniroyal-Elec-0603WAF3601T5E_C22980_front.jpg
C17408 | 0805W8F1000T5E | UNI-ROYAL(Uniroyal Elec) | 0805 |  | 125mW Thick Film Resistors 150V ±100ppm/? ±1% 100? 0805 Chip Resistor - Surface Mount ROHS | yes | 1 | 100 | 0.0018 | 0.01 | https://assets.lcsc.com/images/lcsc/96x96/20221228_UNI-ROYAL-Uniroyal-Elec-0805W8F1000T5E_C17408_front.jpg
C17475 | 0805W8F1502T5E | UNI-ROYAL(Uniroyal Elec) | 0805 |  | 125mW Thick Film Resistors 150V ±100ppm/? ±1% 15k? 0805 Chip Resistor - Surface Mount ROHS | yes | 3 | 100 | 0.0018 | 0.01 | https://assets.lcsc.com/images/lcsc/96x96/20221228_UNI-ROYAL-Uniroyal-Elec-0805W8F1502T5E_C17475_front.jpg
C2894984 | PZ254-2-04-W-8.5 | HCTL | Push-Pull,P=2.54mm |  | 3A Right-Angle Square Pins 2.5mm 8P 6mm -40?~+105? 2.54mm ?? Black 2.54mm 2x4P Push-Pull,P=2.54mm Pin Headers ROHS | yes | 1 | 5 | 0.1097 | 0.11 | https://assets.lcsc.com/images/lcsc/96x96/20230107_HCTL-PZ254-2-04-W-8-5_C2894984_front.jpg
C2894986 | PZ254-2-06-W-8.5 | HCTL | Push-Pull,P=2.54mm |  | 3A Right-Angle Square Pins 2.5mm 12P 6mm -40?~+105? 2.54mm ?? Black 2.54mm 2x6P Push-Pull,P=2.54mm Pin Headers ROHS | yes | 2 | 5 | 0.1707 | 0.34 | https://assets.lcsc.com/images/lcsc/96x96/20230107_HCTL-PZ254-2-06-W-8-5_C2894986_front.jpg
C319160 | U254-051T-4BH83-S1S | XKB Connectivity | SMD |  | 1.8A USB 2.0 1 260? Surface Mount?Right Angle 5P Female -20?~+85? Gold Copper Alloy Micro-B SMD USB Connectors ROHS | yes | 2 | 10 | 0.0672 | 0.13 | https://assets.lcsc.com/images/lcsc/96x96/20181025_XKB-Connectivity-U254-051T-4BH83-S1S_C319160_front.jpg
C10681 | ACS712ELCTR-20A-T | Allegro MicroSystems, LLC | SOIC-8 |  | 20A SOIC-8 Current Sensors ROHS | yes | 1 | 1 | 1.6037 | 1.60 | https://assets.lcsc.com/images/lcsc/96x96/20180914_Allegro-MicroSystems--LLC-ACS712ELCTR-20A-T_C10681_front_10.jpg
C189475 | ATMEGA4809-AFR | Microchip Tech | TQFP-48(7x7) |  | 48KB 1.8V~5.5V AVR 6KB 20MHz FLASH 41 TQFP-48(7x7) Microcontroller Units (MCUs/MPUs/SOCs) ROHS | yes | 1 | 1 | 3.9137 | 3.91 | https://assets.lcsc.com/images/lcsc/96x96/20230905_Microchip-Tech-ATMEGA4809-AFR_C189475_front.jpg
C2156551 | LM4040DIM3-2.5+T | Analog Devices Inc./Maxim Integrated | SOT-23 |  | 2.5V ±1% 15mA Fixed SOT-23 Voltage References ROHS | yes | 1 | 1 | 0.5378 | 0.54 | -
C65110 | MC34063ECD-TR | STMicroelectronics | SOIC-8 |  | Buck-boost type Adjustable 1.25V~38V 3V~40V 1.5A SOIC-8 DC-DC Converters ROHS | yes | 1 | 1 | 0.5728 | 0.57 | https://assets.lcsc.com/images/lcsc/96x96/20221231_STMicroelectronics-MC34063ECD-TR_C65110_front.jpg
C6186 | AMS1117-3.3 | Advanced Monolithic Systems | SOT-223-3 |  | 72dB@(120Hz) 1A Fixed 3.3V Positive electrode SOT-223-3 Linear Voltage Regulators (LDO) ROHS | yes | 1 | 5 | 0.1411 | 0.14 | https://assets.lcsc.com/images/lcsc/96x96/20221228_Advanced-Monolithic-Systems-AMS1117-3-3_C6186_front.jpg
C84681 | CH340C | WCH(Jiangsu Qin Heng) | SOP-16 |  | 2Mbps Transceiver USB 2.0 SOP-16 USB ICs ROHS | yes | 2 | 1 | 0.4996 | 1.00 | https://assets.lcsc.com/images/lcsc/96x96/20221231_WCH-Jiangsu-Qin-Heng-CH340C_C84681_front.jpg
C477829 | WT8266-S5 ESP-12F | Wireless-tag | SMD,16x24mm |  | SMD,16x24mm WiFi Modules ROHS | yes | 1 | 1 | 2.4326 | 2.43 | https://assets.lcsc.com/images/lcsc/96x96/20230119_Wireless-tag-WT8266-S5-ESP-12F_C477829_front.jpg
C917153 | AMS1117-5.0 | JSMSEMI | SOT-223-3 |  | SOT-223-3 Linear Voltage Regulators (LDO) ROHS | yes | 1 | 5 | 0.0910 | 0.09 | https://assets.lcsc.com/images/lcsc/96x96/20230130_JSMSEMI-AMS1117-5-0_C917153_front.jpg
C7603375 | AO4409 | TECH PUBLIC | SOP-8 |  | SOP-8 MOSFETs ROHS | yes | 1 | 5 | 0.2139 | 0.21 | https://assets.lcsc.com/images/lcsc/96x96/20231117_TECH-PUBLIC-AO4409_C7603375_front.jpg
C136682 | K2-1102DP-G3SW-04 | Korean Hroparts Elec | Plugin |  | 6mm 7mm Round Button 50mA Straight 6mm SPST 100M? 100,000 Times 180gf 12V Plugin Tactile Switches ROHS | yes | 4 | 10 | 0.0541 | 0.22 | https://assets.lcsc.com/images/lcsc/96x96/20180914_Korean-Hroparts-Elec-K2-1102DP-G3SW-04_C136682_front.jpg
C916390 | S8050 | JSMSEMI | SOT-23 |  | 25V 300mW 500mA SOT-23 Bipolar Transistors - BJT ROHS | yes | 1 | 100 | 0.0050 | 0.01 | https://assets.lcsc.com/images/lcsc/96x96/20230216_JSMSEMI-S8050_C916390_front.jpg
C2985622 | SI2300 | KUU | SOT-23 |  | 20V 6A 48m?@4.5V,6A 1V@250uA N Channel SOT-23 MOSFETs ROHS | yes | 1 | 20 | 0.0273 | 0.03 | https://assets.lcsc.com/images/lcsc/96x96/20230122_KUU-SI2300_C2985622_front.jpg
C347503 | IRLML2502 | UMW(Youtai Semiconductor Co., Ltd.) | SOT-23 |  | 20V 4.2A 1.25W 45m?@4.5V,4.2A 1.2V@50uA N Channel SOT-23 MOSFETs ROHS | yes | 1 | 5 | 0.0707 | 0.07 | https://assets.lcsc.com/images/lcsc/96x96/20230629_UMW-Youtai-Semiconductor-Co---Ltd--IRLML2502_C347503_front.jpg
C123008 | UMH3NTN | ROHM Semicon | SOT-363 |  | 100@1mA,5V 2 NPN - Pre-Biased 150mW 100mA 50V SOT-363 Digital Transistors ROHS | yes | 1 | 10 | 0.0431 | 0.04 | https://assets.lcsc.com/images/lcsc/96x96/20230101_ROHM-Semicon-UMH3NTN_C123008_front.jpg
C99124 | AOD4184A | Alpha & Omega Semicon | TO-252-2(DPAK) |  | 40V 7m?@10V,20A 2.6V@250uA N Channel TO-252-2(DPAK) MOSFETs ROHS | yes | 1 | 5 | 0.3088 | 0.31 | https://assets.lcsc.com/images/lcsc/96x96/20221231_Alpha---Omega-Semicon-AOD4184A_C99124_front.jpg
C130716 | NCD1206O1 | Foshan NationStar Optoelectronics | 1206 |  | 20mA ?????? 80mcd~220mcd -30?~+85? 589nm~610nm Orange 130° 65mW 1.6V~2.6V 1206 Light Emitting Diodes (LED) ROHS | yes | 3 | 20 | 0.0356 | 0.11 | https://assets.lcsc.com/images/lcsc/96x96/20230102_Foshan-NationStar-Optoelectronics-NCD1206O1_C130716_front.jpg
C239355 | A2541HWR-2x4P | CJT(Changjiang Connectors) | Push-Pull,P=2.54mm |  | 2.54mm 2.54mm ?? Gold 8P Brass Right-Angle 2x4P Push-Pull,P=2.54mm Female Headers ROHS | yes | 1 | 1 | 0.1904 | 0.19 | https://assets.lcsc.com/images/lcsc/96x96/20230111_CJT-Changjiang-Connectors-A2541HWR-2x4P_C239355_front.jpg
C5333437 | A2541HWR-2x6P | CJT(Changjiang Connectors) | Push-Pull,P=2.5mm |  | Push-Pull,P=2.5mm Female Headers ROHS | yes | 2 | 5 | 0.2537 | 0.51 | https://assets.lcsc.com/images/lcsc/96x96/20221230_CJT-Changjiang-Connectors-A2541HWR-2x6P_C5333437_front.jpg
C124418 | B-2200S07P-A120 | Ckmtw(Shenzhen Cankemeng) | Plugin,P=2.54mm |  | 2.54mm Plugin 7P Brass Straight 1x7P Plugin,P=2.54mm Female Headers ROHS | yes | 1 | 5 | 0.1355 | 0.14 | https://assets.lcsc.com/images/lcsc/96x96/20230101_Ckmtw-Shenzhen-Cankemeng-B-2200S07P-A120_C124418_front.jpg
C541850 | PM254V-11-03-H85 | XFCN | Plugin,P=2.54mm |  | 2.54mm Plugin 3P Brass Straight 1x3P Plugin,P=2.54mm Female Headers ROHS | yes | 2 | 5 | 0.0948 | 0.19 | https://assets.lcsc.com/images/lcsc/96x96/20230104_XFCN-PM254V-11-03-H85_C541850_front.jpg
C2718488 | C2718488 | BOOMELE(Boom Precision Elec) | Plugin,P=2.54mm |  | 2.54mm Plugin 3A 4P bronze -40?~+105? Straight 1x4P Top Square Holes Plugin,P=2.54mm Female Headers ROHS | yes | 1 | 10 | 0.0436 | 0.04 | https://assets.lcsc.com/images/lcsc/96x96/20230129_BOOMELE-Boom-Precision-Elec-C2718488_C2718488_front.jpg
C179553 | B5819W | Yenji Elec | SOD-123 |  | 40V 600mV@1A 1A SOD-123 Schottky Barrier Diodes (SBD) ROHS | yes | 2 | 20 | 0.0296 | 0.06 | https://assets.lcsc.com/images/lcsc/96x96/20230111_Yenji-Elec-B5819W_C179553_front.jpg
C77335 | MBR0520 | Jiangsu Changjing Electronics Technology Co., Ltd. | SOD-123 |  | 20V 450mV@500mA 500mA SOD-123 Schottky Barrier Diodes (SBD) ROHS | yes | 6 | 20 | 0.0335 | 0.20 | https://assets.lcsc.com/images/lcsc/96x96/20221231_Jiangsu-Changjing-Electronics-Technology-Co---Ltd--MBR0520_C77335_front.jpg
C442326 | HX25003-2WAP | HX(Zhejiang Yueqing Hongxing Elec) | Push-Pull,P=2.5mm |  | 1x2P 2P XH 1 2.5mm 2 Right-Angle Push-Pull,P=2.5mm Wire To Board / Wire To Wire Connector ROHS | yes | 6 | 50 | 0.0131 | 0.08 | https://assets.lcsc.com/images/lcsc/96x96/20230108_HX-Zhejiang-Yueqing-Hongxing-Elec-HX25003-2WAP_C442326_front.jpg
C15008 | CL31A107MQHNNNE | Samsung Electro-Mechanics | 1206 |  | 6.3V 100uF X5R ±20% 1206 Multilayer Ceramic Capacitors MLCC - SMD/SMT ROHS | yes | 2 | 5 | 0.0671 | 0.13 | https://assets.lcsc.com/images/lcsc/96x96/20221228_Samsung-Electro-Mechanics-CL31A107MQHNNNE_C15008_front.jpg
C124859 | TC212B107M010B | Sunlord | CASE-B-3528 |  | 100uF 10V 1?@100kHz ±20% CASE-B-3528 Tantalum Capacitors ROHS | yes | 3 | 1 | 0.2471 | 0.74 | https://assets.lcsc.com/images/lcsc/96x96/20230102_Sunlord-TC212B107M010B_C124859_front.jpg
C23777 | GR687M035G20RR0VL4FP0 | CX(Dongguan Chengxing Elec) | Plugin,D10xL20mm |  | 680uF 35V ±20% Plugin,D10xL20mm Aluminum Electrolytic Capacitors - Leaded ROHS | yes | 4 | 5 | 0.0867 | 0.35 | https://assets.lcsc.com/images/lcsc/96x96/20221229_CX-Dongguan-Chengxing-Elec-GR687M035G20RR0VL4FP0_C23777_front.jpg
C94599 | MLT-8530 | Jiangsu Huaneng Elec | SMD,8.5x8.5mm |  | Externally Driven 80dB@5V,10cm Magnetic 2.7kHz SMD,8.5x8.5mm Buzzers ROHS | yes | 1 | 5 | 0.2334 | 0.23 | https://assets.lcsc.com/images/lcsc/96x96/20221231_Jiangsu-Huaneng-Elec-MLT-8530_C94599_front.jpg

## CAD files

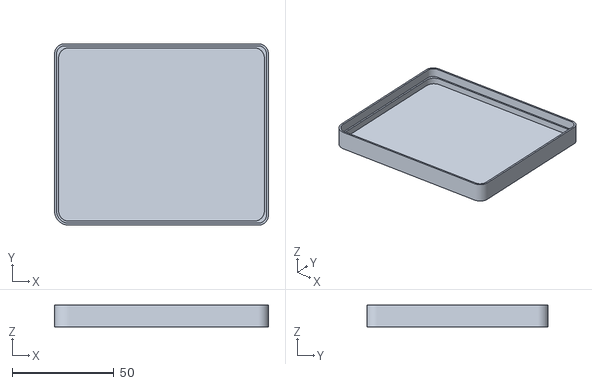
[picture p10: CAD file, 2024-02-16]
Hardware/Case 3D Files/Case Bottom.stl
105.0 x 89.0 x 10.6

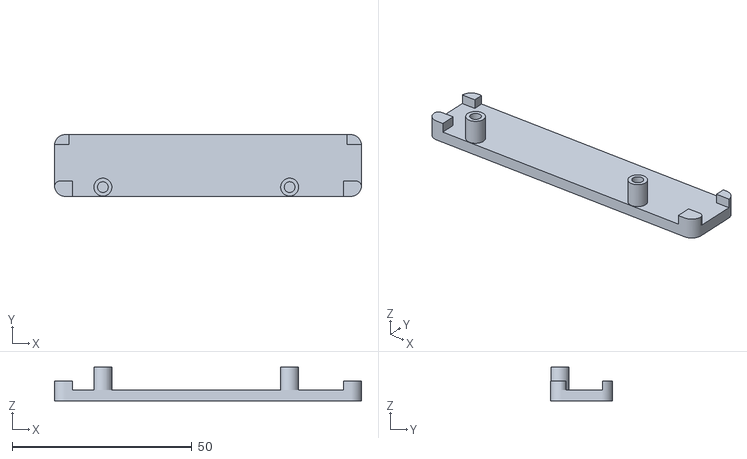
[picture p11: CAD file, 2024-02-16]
Hardware/Case 3D Files/Guard Bottom.stl
85.5 x 17.2 x 9.40

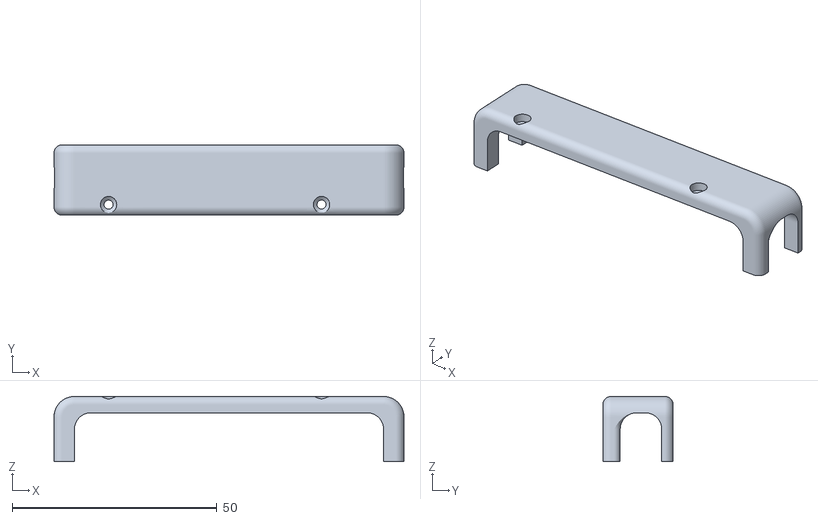
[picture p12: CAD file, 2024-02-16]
Hardware/Case 3D Files/Guard top.stl
85.5 x 17.2 x 15.9

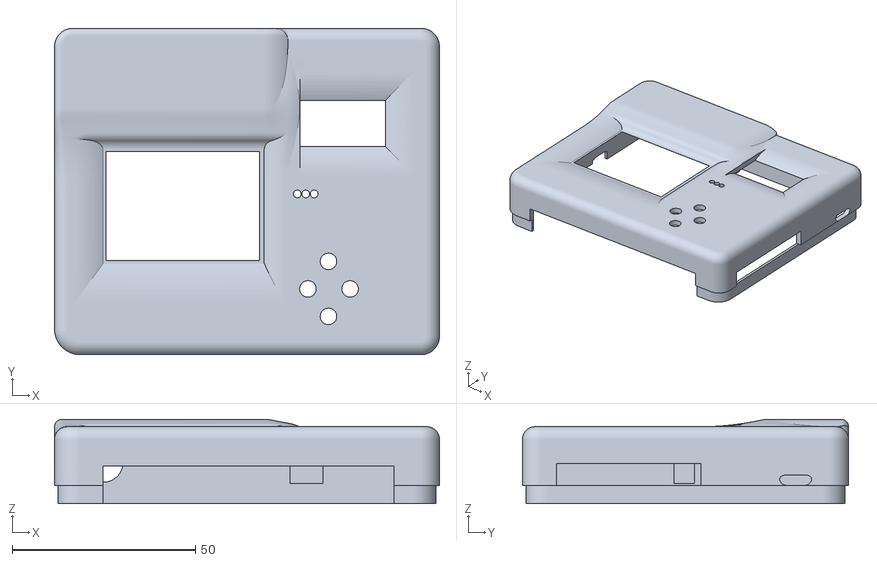
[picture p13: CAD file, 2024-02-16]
Hardware/Case 3D Files/Case Top.stl
105.0 x 89.0 x 23.0

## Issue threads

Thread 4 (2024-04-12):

L1 off by a factor of 10

mafiltenborg, 2024-04-12:
L1 is specified in the schematic (and the BOM) as having 220uH inductance.

However, the proposed component MetalLions CDRH74-220MT (LCSC C133406) is 22uH only.

See https://www.lcsc.com/product-detail/Power-Inductors_MetalLions-CDRH74-220MT_C133406.html
Compare with BOM component 22; L1 spec'd at 220uH.

Which is it: 22 or 220uH? In case it's 220uH I'd suggest changing LCSC component to something suitable, like Murata
45224C:
( https://dk.rs-online.com/web/p/smd-spoler/8004413 - spec https://www.murata.com/en-eu/products/productdetail?partno=45224C )

Closed 2024-05-31.

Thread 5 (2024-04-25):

PCB Thermistor Connector Layout problem

McMega72, 2024-04-25:
The issue occures when attempting to utilize the onboard thermistor of the hotplate.

As depicted in my sketch, the connector links Pin (1,2,3,4) of the control board with Pin (5,6,7,8) of the hotplate, and (5,6,7,8) to (1,2,3,4). It should be (1,2,3,4) to (1,2,3,4) and (5,6,7,8) to (5,6,7,8).

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

As a quick fix, I adjusted the hotplate connector by shifting it down one row, ensuring that only Pin (5,6,7,8) of both boards are connected. Then, I used a jumper to connect both Pin 3 for the 5V supply. In my Picture the jumper is only visible on the Topside.

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

So the connector rows of hotplate should be switched within the layout program.

Closed 2024-05-31.

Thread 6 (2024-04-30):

Would this project be possible to solder using a soldering iron

h4z-dev, 2024-04-30:
I'm starting to learn electronics and have a soldering iron and am decent with tht components and was wondering the viability of hand soldering the SMD components?
:)

vactomas, 2024-04-30:
Hey, I haven't made this project yet, but quickly going through the BOM I see 0603 or 0805 package size components which can be hand soldered. I made a keyboard and soldered many 0603 diodes and it was fine. If you are not sure, you can always buy SMD soldering kit to try it out

arwidcool, 2024-04-30:
Yes, its possible, totally! easy? no. The atmega is tricky to solder.  There is also a problem with the layout of the right hand connector I need to fix, but havent had time.

Closed 2024-05-31.

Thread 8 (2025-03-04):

Thermistor documentation

oh9vd, 2025-03-04:
Documentation:
"Thermistor thermistor4(THERMISTOR4_PIN, 564, ThermistorZ_Placement::BOTTOM, ThermistorXY_Placement::MIDDLE_HIGH_TEMP); //-> 564Kohm set refrence // 564R reference = Best accuracy around 210C"
Is the 564Kohm value correct? What does mean // 564R reference? Can the Thermistor and trimmer settings be clearer?

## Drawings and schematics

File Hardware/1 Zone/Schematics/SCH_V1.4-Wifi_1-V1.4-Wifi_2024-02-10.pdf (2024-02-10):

# +5V GND THERMISTOR⁴ THERMISTOR³ THERMISTOR²

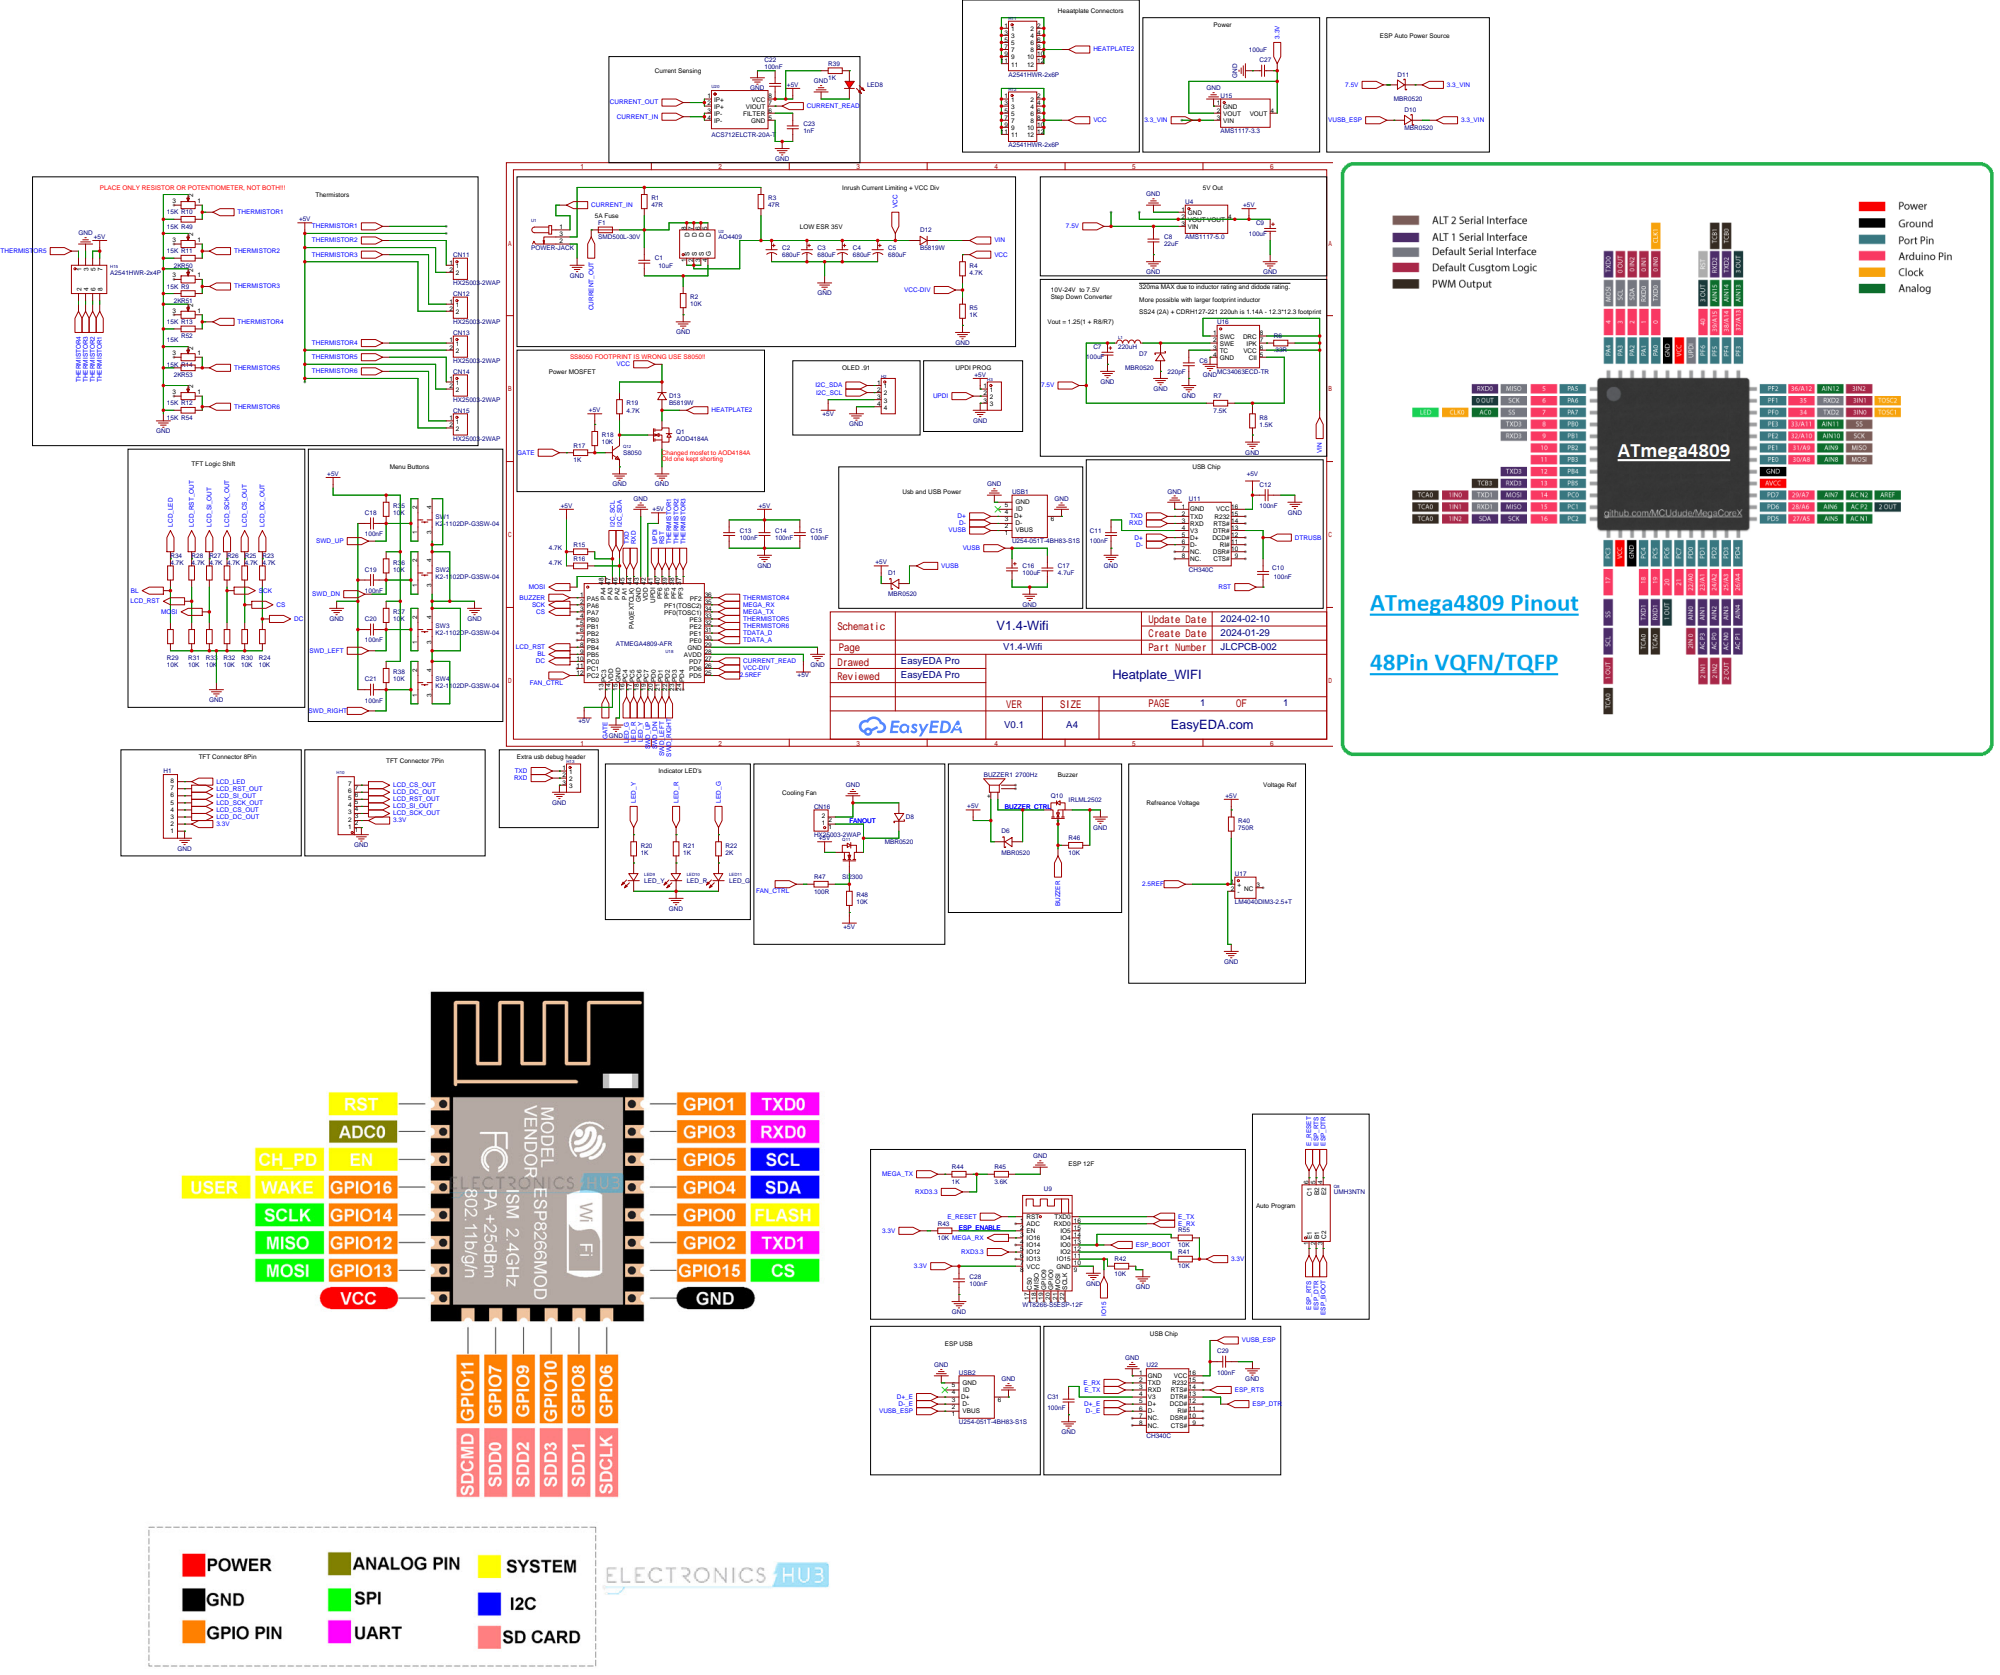
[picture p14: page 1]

ESP Auto Power Source

PLACE ONLY RESISTOR OR POTENTIOMETER, NOT BOTH!!!

GND
320ma MAX due to inductor rating and didode rating.
More possible with larger footprint inductor
SS24 (2A) + CDRH127-221 220uh is 1.14A - 12.3*12.3 footprint

SS8050 FOOTPRINT IS WRONG USE S8050!!
Power MOSFET

Usb and USB Power

Extra usb debug header
TXD
RXD

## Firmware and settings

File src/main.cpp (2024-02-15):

#include <Arduino.h>
#include "ArduPID.h"
#include <Adafruit_GFX.h>
#include <voltageReference/AnalogRef.h>
#include <Wire.h>
#include <thermistors/Thermistor.h>
#include "buttons/Buttons.h"
#include "leds/leds.h"
#include "reflow.h"
#include "displays/oled.h"
#include "displays/tft.h"
#include "PID/PidController.h"
#include "globals.h"
#include "EEPROMDataManager.h"
#include "tools/ExecutionTimer.h"
#include "StopWatch.h"
#include "thermistors/Thermistor.h"
#include "Current/CurrentMonitor.h"

#define MOSTFET_PIN 17

double currentTemp = 0;
double targetTemp = 60;
double pwmValue = 255;

ExecutionTimer executionTimer;

CurrentMonitor currentMonitor = CurrentMonitor();

TemperatureController tempController;

Buttons buttons = Buttons();
LEDS leds = LEDS();
// Declare the PID
ArduPID PID;
OledDisplay oled = OledDisplay();

TFT_Display tftDisplay;

StopWatch thermTimer = StopWatch();
StopWatch thermMilisTimer = StopWatch();

void setup()
{

  pinMode(MOSTFET_PIN, OUTPUT);
  analogWrite(MOSTFET_PIN, 255); // VERY IMPORTANT, DONT CHANGE! 255=off, 0=full power

  Serial.begin(38400);

  // Serial.println("Starting OLED");

  // Set PWM frequency to 64 kHz
  analogWriteFrequency(64);

  buttons.setup();
  leds.setup();
  oled.setup();
  eepromDataManager.setup();

  reflowProcessState.set(ReflowProcessState::USER_INPUT);

  tempController.checkPluggedInThermistors();

  tftDisplay.start();

  thermTimer.setResolution(StopWatch::Resolution::MILLIS);

  thermMilisTimer.setResolution(StopWatch::Resolution::MILLIS);

  Serial.println("Setup done");

  // currentMonitor.calculateMaxPwm();
}
void loop()
{

  //  executionTimer.start();

  // Return the button that changed state
  Pair<ButtonKind, StateChangeEvent<ButtonState>> *k = buttons.handleButtons();
  ReflowProcessState state = reflowProcessState.get();
  if (k != NULL)
  {
    if (state == ReflowProcessState::USER_INPUT)
    {
      leds.handleButtonStateChange(*k);
      oled.handleButtonStateChange(*k);
    }
    else if (state >= ReflowProcessState::PREHEAT && state <= ReflowProcessState::COOL)
    {
      if (k->first == ButtonKind::BACK && k->second.to == ButtonState::PRESSED)
      {
        // STOP REFLOW and restart
        reflowProcessState.set(ReflowProcessState::USER_INPUT);
        pidController.stop();
        leds.reset();
      }
    }
    else if (state == ReflowProcessState::DONE)
    {
      oled.handleButtonStateChange(*k);
    }
  }
  ReflowProcessState newState = reflowProcessState.get();

  if (newState != state)
  {
    debugLine("State changed from " + String(STATE_STR(state)) + " to " + String(STATE_STR(newState)));
    // State changed from state to newState (user input or wifi input needs to be above here)
    if (newState == ReflowProcessState::PREHEAT)
    {

      tftDisplay.init(&chosenReflowProfile);
      tempController.checkPluggedInThermistors();

      chosenReflowProfile.start(tempController.getPlateTemperature());
      // Start the PID
      pidController.start();
      thermMilisTimer.start();
      thermTimer.start();
      // Serial.println("Time,Therm1,Therm2,Therm3,Therm4,Therm5,Therm6,,Scaling1,Scaling2,Scaling3,Scaling4,Scaling5,Scaling6,Averaged1,Weighting1,Weighting2,Weighting3");
    }
  }
  state = newState;

  leds.loop();
  oled.loop();

  if (state >= ReflowProcessState::PREHEAT && state <= ReflowProcessState::COOL)
  {

    pidController.loop();
    pidController.debug();
    float amps = currentMonitor.getSystemCurrentAmps();
    Serial.println("Current: " + String(amps));
    float inVoltage = analogRef.calculateInputVoltage();
    Serial.println("Voltage: " + String(inVoltage));
    // #ifdef DEBUG

    //   #endif

    tftDisplay.drawRealTemp(pidController.getInput(), chosenReflowProfile.getPercentage());
    ReflowStep step = chosenReflowProfile.reflowStep();
    // Here we draw the actual temp vs time to the display

    // if (thermTimer.elapsed() > 1)
    // {

    //   Serial.print(thermTimer.elapsed());
    //   Serial.print(",");
    //   float temp1 = thermistor1.getTemperature();
    //   float temp2 = thermistor2.getTemperature();
    //   float temp3 = thermistor3.getTemperature();
    //   float temp4 = thermistor4.getTemperature();
    //   float temp5 = thermistor5.getTemperature();
    //   float temp6 = thermistor6.getTemperature();
    //   Serial.print(temp1);
    //   Serial.print(",");
    //   Serial.print(temp2);
    //   Serial.print(",");
    //   Serial.print(temp3);
    //   Serial.print(",");
    //   Serial.print(temp4);
    //   Serial.print(",");
    //   Serial.print(temp5);
    //   Serial.print(",");
    //   Serial.print(temp6);
    //   Serial.print(",");
    //   Serial.print(thermistor1.scalingFactor);
    //   Serial.print(",");
    //   Serial.print(thermistor2.scalingFactor);
    //   Serial.print(",");
    //   Serial.print(thermistor3.scalingFactor);
    //   Serial.print(",");
    //   Serial.print(thermistor4.scalingFactor);
    //   Serial.print(",");
    //   Serial.print(thermistor5.scalingFactor);
    //   Serial.print(",");
    //   Serial.print(thermistor6.scalingFactor);
    //   Serial.print(",");

    //   float values[] = {temp2,temp3,temp4};
    //   float weights[] = {thermistor2.getWeightingFactor(),thermistor3.getWeightingFactor(),thermistor4.getWeightingFactor()};
    //   uint8_t length = 3;
    //   float averaged = TemperatureController::getWeightedAverage(values, weights, length);
    //   Serial.print(averaged);
    //   Serial.print(",");
    //   Serial.print(weights[0]);
    //   Serial.print(",");
    //   Serial.print(weights[1]);
    //   Serial.print(",");
    //   Serial.print(weights[2]);
    //   Serial.print(",");
    //   Serial.println();
    // Serial.print(",");
    // Serial.print(thermistor1.getWeightingFactor());
    // Serial.print(",");
    // Serial.print(thermistor2.getWeightingFactor());
    // Serial.print(",");
    // Serial.print(thermistor3.getWeightingFactor());
    // Serial.print(",");
    // Serial.print(thermistor4.getWeightingFactor());
    //}

    if (step.state != newState)
    {
      reflowProcessState.set(step.state);
      if (step.state == ReflowProcessState::DONE)
      {
        pidController.stop();
      }
    }
  }

  //  executionTimer.stop();
}

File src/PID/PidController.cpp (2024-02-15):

#include "PidController.h"
#include "globals.h"
#define MOSTFET_PIN 17
#include "voltageReference/AnalogRef.h"
#include "thermistors/TemperatureController.h"

extern AnalogRef analogRef;

extern TemperatureController tempController;

PidController::PidController(PidControllerData *data)
{

    this->data = data;

    controller.begin(&(this->data->currentTemp), &(this->data->setPoint), &(this->data->targetTemp), PID_P, PID_I, PID_D);
    //  controller.reverse();
    controller.setOutputLimits(PID_OUTPUT_MIN, PID_OUTPUT_MAX);
    controller.setSampleTime(PID_SAMPLE_TIME);
    controller.setWindUpLimits(PID_WINDUP_MIN, PID_WINDUP_MAX);
}

double *PidController::compute()
{

    controller.compute();

    return controller.output;
}

void PidController::debug()
{

    controller.debug(&Serial, " ", PRINT_INPUT |      // Can include or comment out any of these terms to print
                                       PRINT_OUTPUT | // in the Serial plotter
                                       PRINT_SETPOINT | PRINT_BIAS | PRINT_P | PRINT_I | PRINT_D);
}

void PidController::loop()

{
    data->targetTemp = chosenReflowProfile.getTargetTemp();

    // data->currentTemp = thermistor1.getTemperature();

    data->currentTemp = tempController.getPlateTemperature();

    // float sysVoltage = analogRef.calculateSystemVoltage();

    float inVoltage = analogRef.calculateInputVoltage();
    compute();

    // Reverseal of the PWM value is needed because the PID controller is set to work with a normal direction, Creates for a better PID control
    // 255= off, 0=full power
    analogWrite(MOSTFET_PIN, 255 - data->setPoint);
}

void PidController::stop()
{
    data->targetTemp = 0; // should not be needed but why not? --- Its needed it randomly starts again and sometimes goes to heat the plate
                          // STOP --> Always use analog write for sanity- Keep PWM pins labled analogWrite -- Writing it LOW will KEEP IT ON

    analogWrite(MOSTFET_PIN, 255); // VERY IMPORTANT, DONT CHANGE!
    controller.reset();
    controller.stop();
}

void PidController::start()
{
    controller.start();
}

double *PidController::getInput()
{
    return controller.input;
}

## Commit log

2024-01-25 Refactor Buttons
2024-01-26 refactored buttons to be more robust.
2024-01-26 Changed handing on LED's and its handled outside of main loop now
2024-01-26 Added all 6 thermistors and cleaned up the AnalogRef file
2024-01-26 Refactor button and LED handling
2024-01-26 Fixed LED colors
2024-01-27 Fixed the reflow.h file. It should have .cpp as well not just .h
    [PidController.cpp, Thermistor.h, main.cpp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]
2024-01-27 Fixed glitch where the PID would randomly start again
    [PidController.cpp, main.cpp]
2024-01-27 Added timer to check execution time of codee
2024-01-27 Playing around with PID so we can hit 210C profile
2024-01-27 Tweaked PID loop
2024-01-27 fix leds
2024-01-27 Very important!!!!!!! PLATE OFF= ANALOGWRITE 255
2024-01-27 Working on adding thermistors with some info
2024-01-27 Added Z and XY coordinates for Thermistor placment
2024-01-27 Fixed menu for Thermistor resistence made it show Kohm with 2 decimal points
    [Thermistor.h]
2024-01-27 Added logic for Temperature Controller and Global debug Flag for Serial Messages
2024-01-27 Added In VOltage to OLED Reflow stage (Important because it shows if your Power supply is not giving enogh voltage)
2024-01-28 refactor reflow on millis for better resolution + fix led + pinleds +
    [PidController.cpp, leds.h, main.cpp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]
2024-01-28 Fixed all bugs for overflow in reflow.h Bug was caused by multipling a uint_16t or uint_32t or uint_8t BEFORE casting it to a float or a unit that can handle the number. Type casting should ONLY be d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
    [PidController.cpp, leds.h, main.cpp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]
2024-01-28 Continuing work on TFT and Fixed bug where LEDS kept blinking if the user cancels while in reflow stage
    [leds.h, main.cpp, tft.h]
2024-01-28 Fixed issue of when using Half sine the next step would start at the MAX of the sign (middle) rather then where it ends
    [reflow.h]
2024-01-28 Implimented drawing the line. 2 options-> Pixel by pixel or a line. Line works better. It starts at 0,0 of graph and then the next value read is the new x,y target and saved last one as start. It dra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
2024-01-28 switch to percentages and reflow refactor.
2024-01-28 fixed led order again + migrated to uint16_t since now proper typecasting is in place.
    [leds.h, reflow.h]
2024-01-28 fix temp from prev soldering and also add startTimes
    [reflow.h]
2024-01-28 Added some function to thermistor
2024-01-30 Update thermistor placement and pin assignments and impilmented Thermistor Positioning lookup tables that are calculated from the top middle sensor. Need to gather more data and then add the lookup t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
2024-01-31 Tuning the weighting factor of bottom placed thermistors and set resistence
2024-02-01 Added temperature controller as main calc for temp used by PID and all display menus where applicable. Adjusted lookup table for opitions and added the PID settings to global
2024-02-01 Un-reveresed the PID logic, a bit easier to follow now
2024-02-10 Adding Files for Hardware - Updating Readme
    [BOM_V1.4-Wifi_V1.4-Wifi_2024-02-10.xlsx]
2024-02-10 Added some filed and updated the readme and globalc.cpp
    [BOM_V1.4-Wifi_V1.4-Wifi_2024-02-10.xlsx]
2024-02-15 Adding current monitoring code
2024-02-16 Upated Readme, current monitoring code and Case 3D files
    [Case Bottom.stl, Case Top.stl, Guard Bottom.stl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]
2024-05-31 Fixes #4 and Fixes #5 . Added gerber 1.4.1 for hotplate with corrected playout and removed 1.4 and fixed Inductor note in the BOM
    [BOM_V1.4-Wifi_V1.4-Wifi_2024-02-10.xlsx]
